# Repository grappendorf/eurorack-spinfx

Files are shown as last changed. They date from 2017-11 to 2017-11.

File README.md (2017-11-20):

Eurorack SpinFX
===============

An effects module based on the [Spin FV-1](http://www.spinsemi.com/products.html) IC.

The circuit is built from the reference design in the 
[data sheet](http://www.spinsemi.com/Products/datasheets/spn1001/FV-1.pdf) with some 
standard input and output signal level translation. I've also added a slightly over-engineerd 
program number display.

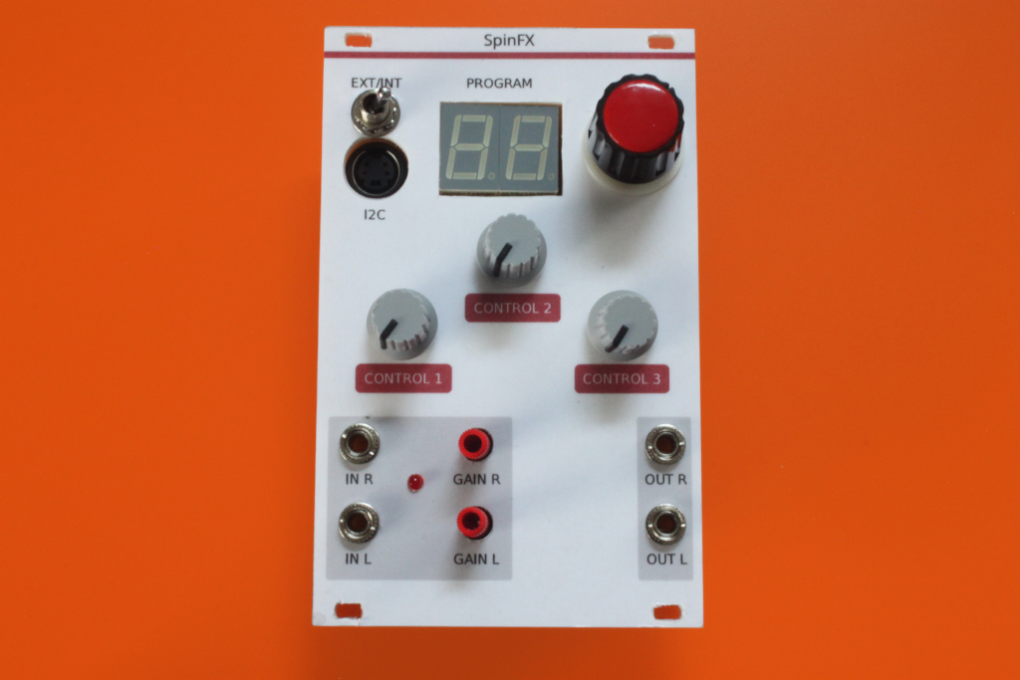
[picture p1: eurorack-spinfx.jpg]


More information can be found on the
[project website](http://www.grappendorf.net/projects/eurorack/eurorack-spinfx.html).

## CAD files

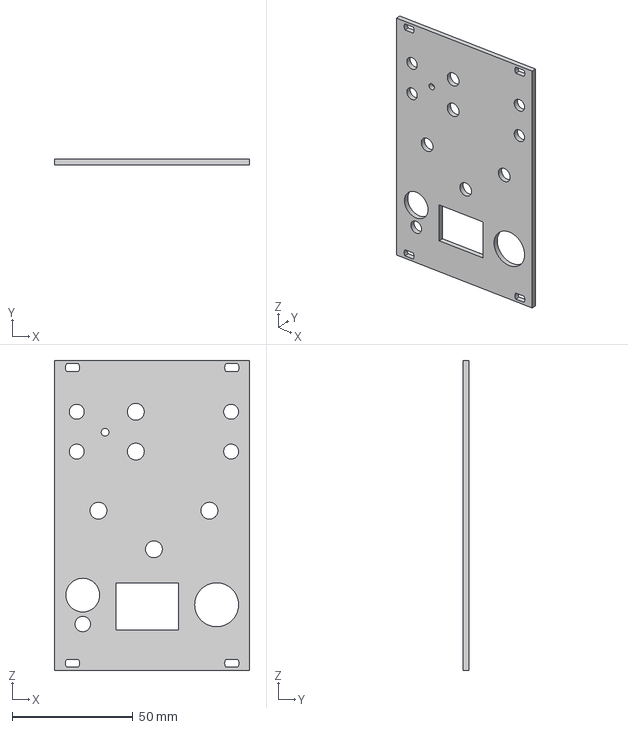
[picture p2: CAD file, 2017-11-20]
panel/Eurorack SpinFX.step
80.9 x 2.50 x 128.5 mm

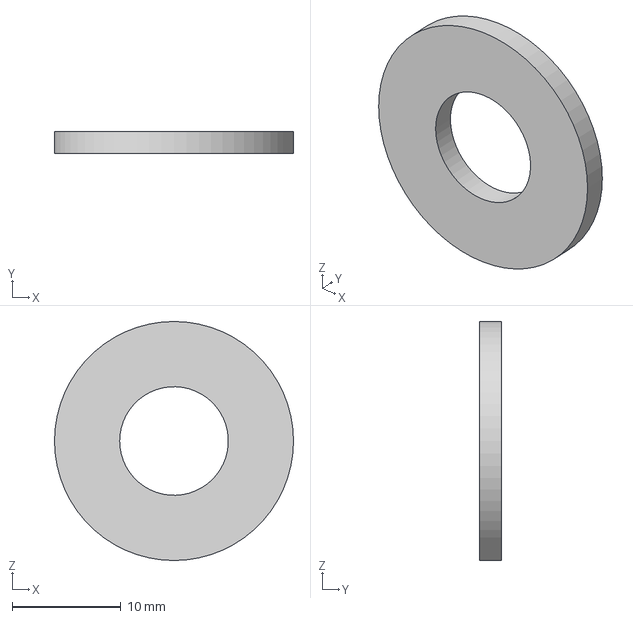
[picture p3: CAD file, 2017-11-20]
panel/Washer M10 20mm 2mm.step
22.0 x 2.00 x 22.0 mm

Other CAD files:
panel/Eurorack SpinFX.f3d
panel/Eurorack SpinFX.stl
panel/Washer M10 20mm 2mm.f3d
panel/Washer M10 20mm 2mm.stl

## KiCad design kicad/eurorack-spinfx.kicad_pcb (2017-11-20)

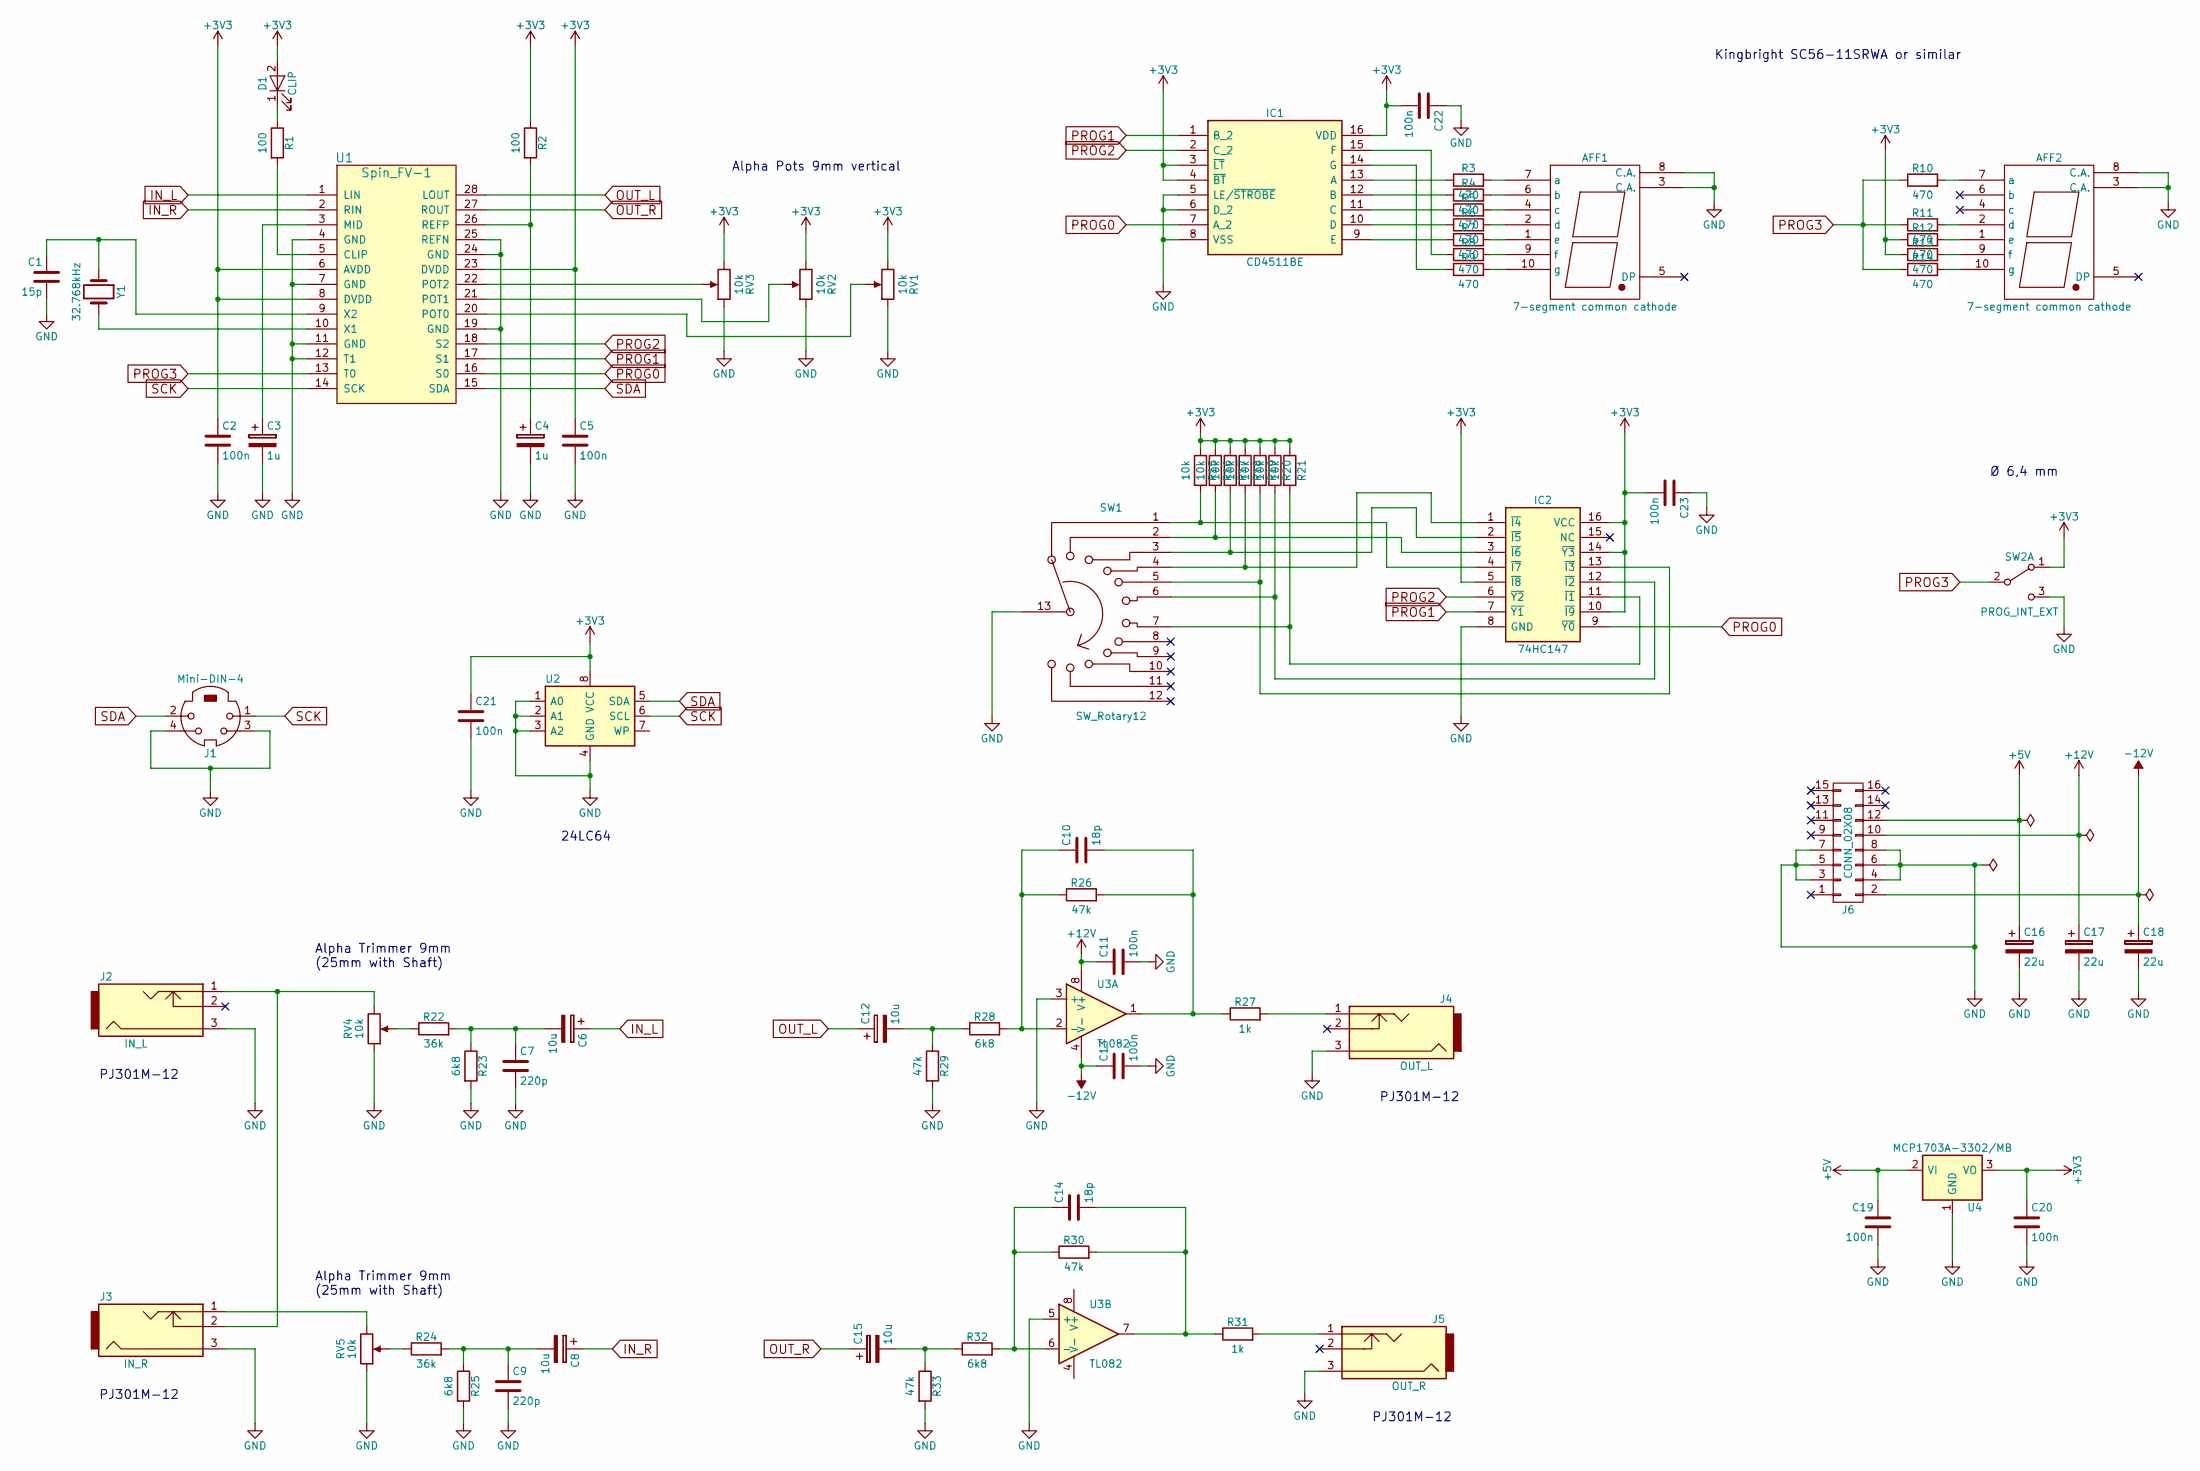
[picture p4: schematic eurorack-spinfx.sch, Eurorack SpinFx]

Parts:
AFF1, AFF2: 7-segment common cathode; 7SegmentLED_LTS6760_LTS6780
C1: 15p; C_1206
C2, C5, C11, C13, C19, C20, C21, C22, C23: 100n; C_1206
C3, C4: 1u; CP_Elec_4x5.8
C6, C8, C12, C15: 10u; CP_Elec_4x5.8
C7, C9: 220p; C_1206
C10, C14: 18p; C_1206
C16, C17, C18: 22u; CP_Elec_6.3x5.8
D1: CLIP; LED_D3.0mm
IC1: CD4511BE; SOIC-16_3.9x9.9mm_Pitch1.27mm; Manufacturer_Part_Number CD4511BE
IC2: 74HC147; SOIC-16_3.9x9.9mm_Pitch1.27mm; Manufacturer_Part_Number CD74HC147EE4
J1: Mini-DIN-4; Mini_Din_4
J2: IN_L; PJ301M-12
J3: IN_R; PJ301M-12
J4: OUT_L; PJ301M-12
J5: OUT_R; PJ301M-12
J6: CONN_02X08; Eurorack_Power_2x8_SMD
R1, R2: 100; R_1206
R3, R4, R5, R6, R7, R8, R9, R10, R11, R12, R13, R14: 470; R_1206
R15, R16, R17, R18, R19, R20, R21: 10k; R_1206
R22, R24: 36k; R_1206
R23, R25, R28, R32: 6k8; R_1206
R26, R29, R30, R33: 47k; R_1206
R27, R31: 1k; R_1206
RV1, RV2, RV3: 10k; Alpha_9mm_Pot
RV4, RV5: 10k; Alpha_9mm_Trimmer_25mm_with_Shaft
SW1: SW_Rotary12; ROTARY_SWITCH_LORLINCK1049
SW2: PROG_INT_EXT; Switch_Eledis_1x_On_On
U1: Spin_FV-1; SOIC-28W_7.5x17.9mm_Pitch1.27mm
U2: 24LC64; SO-8_5.3x6.2mm_Pitch1.27mm
U3: TL082; SO-8_5.3x6.2mm_Pitch1.27mm
U4: MCP1703A-3302/MB; SOT-89-3
Y1: 32.768kHz; Crystal_C26-LF_d2.1mm_l6.5mm_Horizontal_1EP_style1

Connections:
+3V3: C2.1, C5.1, C20.1, C21.1, C22.2, C23.2, D1.2 (A), IC1.3 (~LT), IC1.4 (~BT), IC1.16 (VDD), IC2.5 (~I8), IC2.10 (~I9), IC2.14 (~Y3), IC2.16 (VCC), R2.1, R12.1, R13.1, R15.1, R16.1, R17.1, R18.1, R19.1, R20.1, R21.1, RV1.3, RV2.3, RV3.3, SW2.1 (A), U1.6 (AVDD), U1.8 (DVDD), U1.23 (DVDD), U2.8 (VCC), U4.3 (VO)
+5V: C16.1, C19.1, J6.12, U4.2 (VI)
+12V: C11.1, C17.1, J6.10, U3.8 (V+)
-12V: C13.1, C18.1, J6.2, U3.4 (V-)
GND: AFF1.3 (C.A.), AFF1.8 (C.A.), AFF2.3 (C.A.), AFF2.8 (C.A.), C1.2, C2.2, C3.2, C4.2, C5.2, C7.2, C9.2, C11.2, C13.2, C16.2, C17.2, C18.2, C19.2, C20.2, C21.2, C22.1, C23.1, IC1.5 (LE/~STROBE), IC1.6 (D_2), IC1.8 (VSS), IC2.8 (GND), J1.3, J1.4, J2.3, J3.3, J4.3, J5.3, J6.3, J6.4, J6.5, J6.6, J6.7, J6.8, R23.2, R25.2, R29.2, R33.2, RV1.1, RV2.1, RV3.1, RV4.1, RV5.1, SW1.13, SW2.3 (C), U1.4 (GND), U1.7 (GND), U1.11 (GND), U1.12 (T1), U1.19 (GND), U1.24 (GND), U1.25 (REFN), U2.1 (A0), U2.2 (A1), U2.3 (A2), U2.4 (GND), U3.3 (+), U3.5 (+), U4.1 (GND)
IN_L: C6.1, U1.1 (LIN)
IN_R: C8.1, U1.2 (RIN)
unnamed: AFF1.1 (e), R7.2
unnamed: AFF1.2 (d), R6.2
unnamed: AFF1.4 (c), R5.2
unnamed: AFF1.6 (b), R4.2
unnamed: AFF1.7 (a), R3.2
unnamed: AFF1.9 (f), R8.2
unnamed: AFF1.10 (g), R9.2
unnamed: AFF2.1 (e), R12.2
unnamed: AFF2.2 (d), R11.2
unnamed: AFF2.7 (a), R10.2
unnamed: AFF2.9 (f), R13.2
unnamed: AFF2.10 (g), R14.2
unnamed: C1.1, U1.9 (X2), Y1.1
unnamed: C3.1, U1.3 (MID)
unnamed: C4.1, R2.2, U1.26 (REFP)
unnamed: C6.2, C7.1, R22.2, R23.1
unnamed: C8.2, C9.1, R24.2, R25.1
unnamed: C10.1, R26.1, R28.2, U3.2 (-)
unnamed: C10.2, R26.2, R27.1, U3.1
unnamed: C12.2, R28.1, R29.1
unnamed: C14.1, R30.1, R32.2, U3.6 (-)
unnamed: C14.2, R30.2, R31.1, U3.7
unnamed: C15.2, R32.1, R33.1
unnamed: D1.1 (K), R1.1
unnamed: IC1.9 (E), R7.1
unnamed: IC1.10 (D), R6.1
unnamed: IC1.11 (C), R5.1
unnamed: IC1.12 (B), R4.1
unnamed: IC1.13 (A), R3.1
unnamed: IC1.14 (G), R9.1
unnamed: IC1.15 (F), R8.1
unnamed: IC2.1 (~I4), R18.2, SW1.4
unnamed: IC2.2 (~I5), R17.2, SW1.3
unnamed: IC2.3 (~I6), R16.2, SW1.2
unnamed: IC2.4 (~I7), R15.2, SW1.1
unnamed: IC2.11 (~I1), R21.2, SW1.7
unnamed: IC2.12 (~I2), R20.2, SW1.6
unnamed: IC2.13 (~I3), R19.2, SW1.5
unnamed: J2.1, J3.2, RV4.3
unnamed: J3.1, RV5.3
unnamed: J4.1, R27.2
unnamed: J5.1, R31.2
unnamed: R1.2, U1.5 (CLIP)
unnamed: R22.1, RV4.2
unnamed: R24.1, RV5.2
unnamed: RV1.2, U1.20 (POT0)
unnamed: RV2.2, U1.21 (POT1)
unnamed: RV3.2, U1.22 (POT2)
unnamed: U1.10 (X1), Y1.2
OUT_L: C12.1, U1.28 (LOUT)
OUT_R: C15.1, U1.27 (ROUT)
PROG0: IC1.7 (A_2), IC2.9 (~Y0), U1.16 (S0)
PROG1: IC1.1 (B_2), IC2.7 (~Y1), U1.17 (S1)
PROG2: IC1.2 (C_2), IC2.6 (~Y2), U1.18 (S2)
PROG3: R10.1, R11.1, R14.1, SW2.2 (B), U1.13 (T0)
SCK: J1.1, U1.14 (SCK), U2.6 (SCL)
SDA: J1.2, U1.15 (SDA), U2.5 (SDA)

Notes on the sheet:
Alpha Trimmer 9mm (25mm with Shaft)
Alpha Pots 9mm vertical
Kingbright SC56-11SRWA or similar
Ø 6,4 mm
PJ301M-12
24LC64

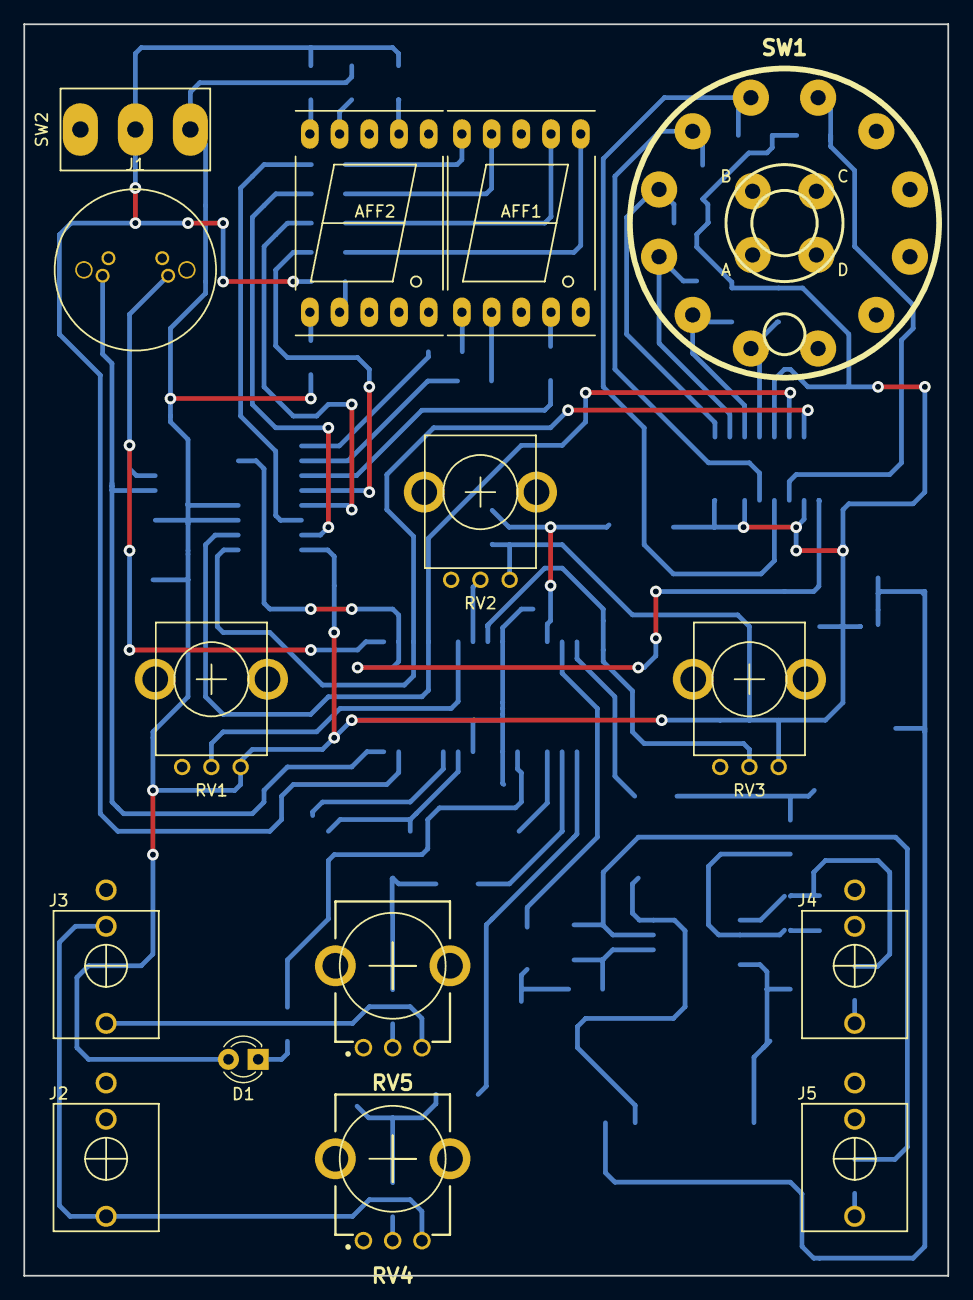
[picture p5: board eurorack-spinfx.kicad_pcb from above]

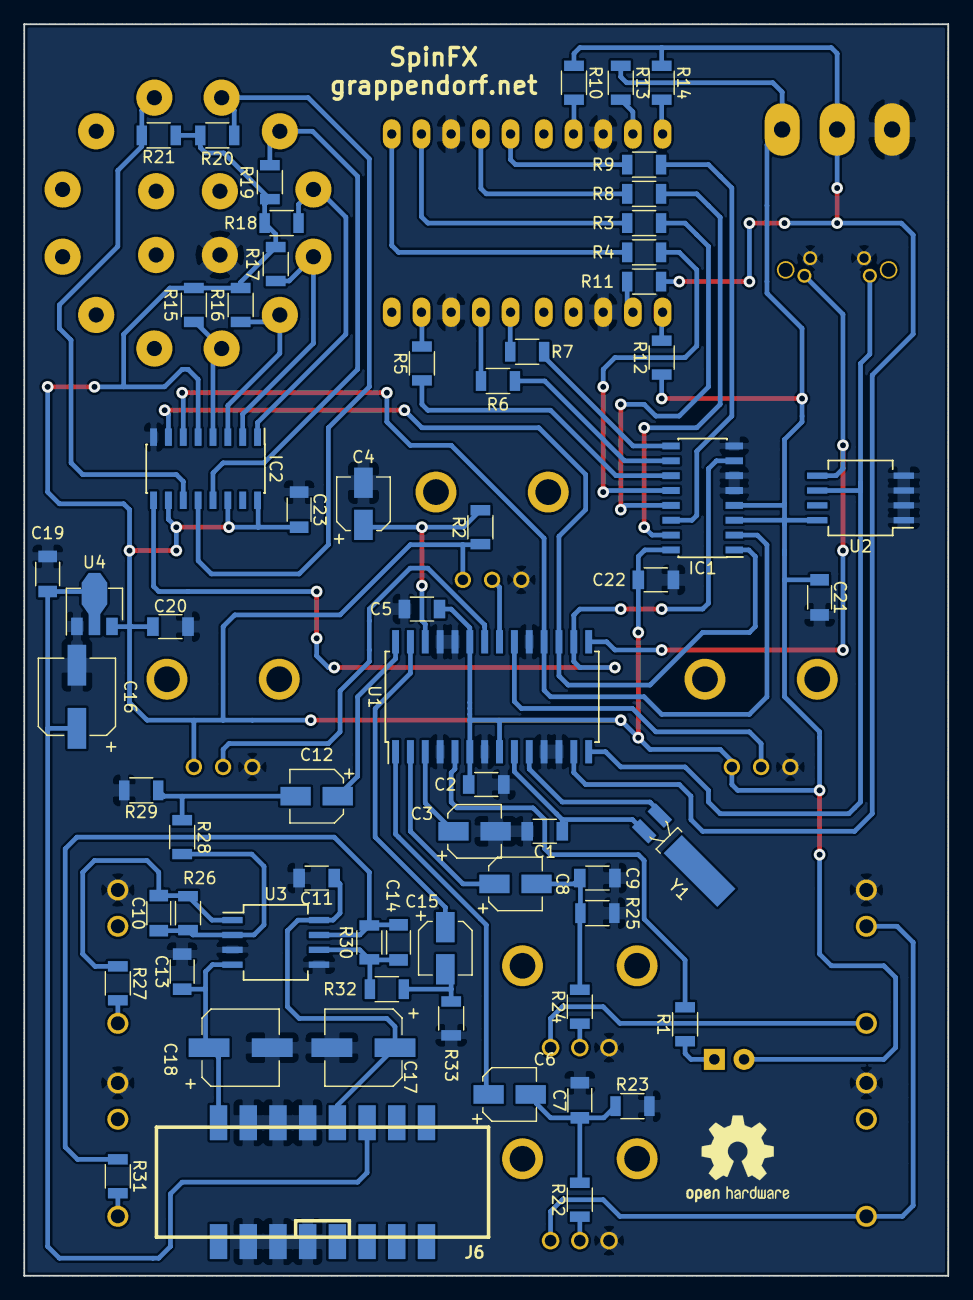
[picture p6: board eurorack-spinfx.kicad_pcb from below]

Board: 2 copper layers, 79.0 x 107.0 mm, 79 parts (64 on the bottom side), 64 nets.
